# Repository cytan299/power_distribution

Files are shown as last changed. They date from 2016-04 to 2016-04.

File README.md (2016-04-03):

# Power Distribution Unit For Astrophotography

by C.Y. Tan 2016

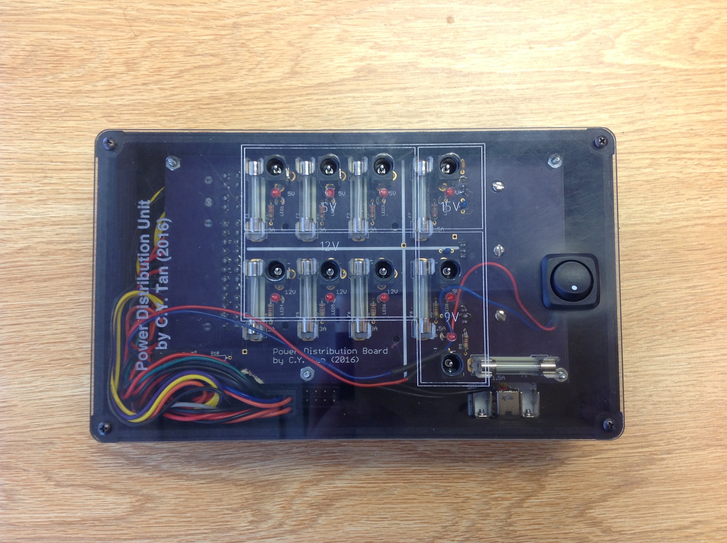
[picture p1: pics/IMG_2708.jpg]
Power Distribution Unit


I got really annoyed with the number of power bricks (or wall-warts)
that were required power my astrophotography setup:

* **LX200** 18V power supply. 
* **SBIG ST8300C** 12V power supply.
* **Field DeRotator** 9V power supply.
* **Dew Heater** 5V power supply.
* **Flat field box** 9V power supply.

I decided to consolidate the above into one box but with enough spare
outlets for future expansion.

## Goal

The goal is to build a power distribution unit that replaces all the
wall-warts that are necessary for running my astrophotography
setup. It should have extra outlets so that it can be used to power
other pieces of equipment in the future. All the outlets have to be
fused to protect itself as well as the connected equipment.

## Design

The power distribution unit is powered by a

* [External 240W 19.5V slim PA-9E PC supply](http://www.amazon.com/Original-PA-9E-Replacement-adapter-Notebook/dp/B00AVMYMUG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).

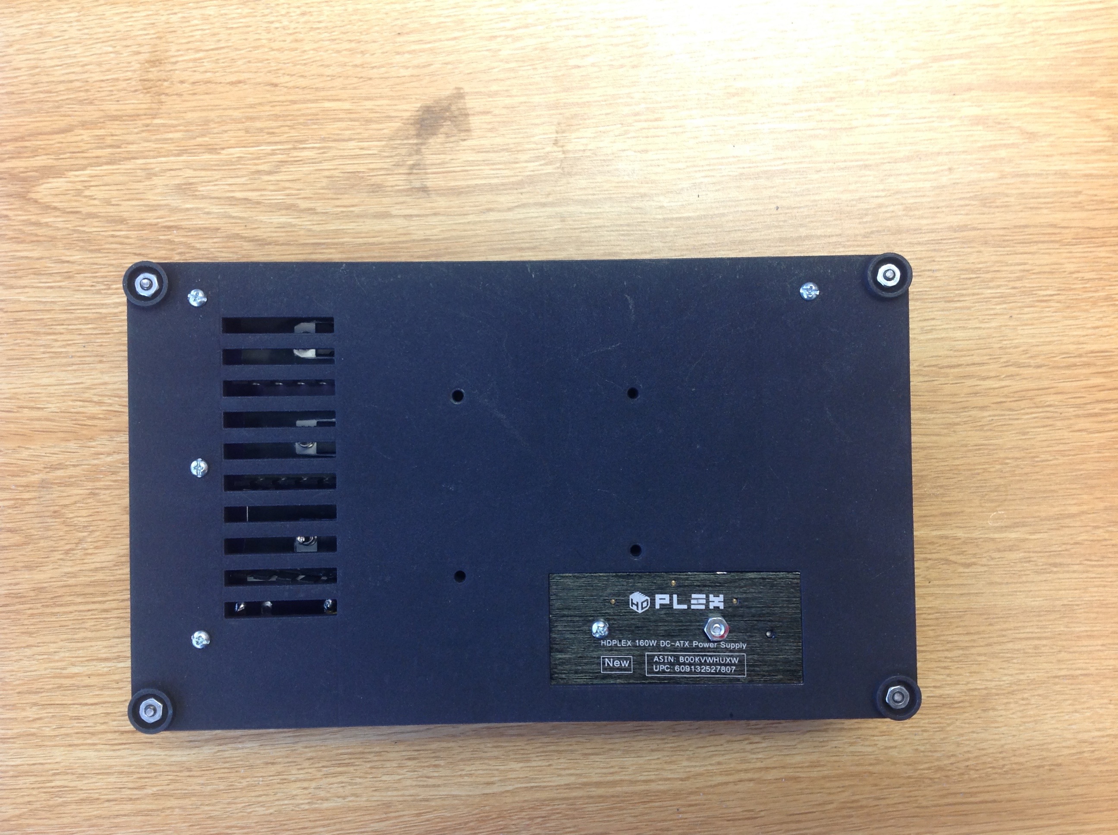
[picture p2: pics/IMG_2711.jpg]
Plex


The 19.5V from the above supply is connected to an internal fanless
[HDPLEX 160W ATX DC power supply](http://www.amazon.com/HDPLEX-DC-ATX-Power-Supply-16V-24V/dp/B00KVWHUXW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). The 5V and 12V supplies come directly from
the PLEX. The other 9V is linearly regulated from the 12V and the 15V
is linearly regulated from the 19.5V input voltage. The available voltage
outlets are listed below:

* Three 5V outlets
* Three 12V outlets
* Two 9 V outlets
* One 15 V outlet. I used this to power my LX200 classic. Although the
  front panel says that the voltage should be 18V, sources on the [web](http://www.skymtn.com/mapug-astronomy/MAPUG/Battery1.htm#anchor318436)
  recommend that a lower voltage be used to power it. Therefore I have
  reduced the voltage from 18V to 15V. Note: I was really shocked to
  measure >20V coming out from the Meade power supply for my LX200!

## Support

This is unsupported hardware. Build at your own peril! :)

You can submit questions or bug reports using the
[issues](https://github.com/cytan299/power_distribution/issues) tab on
the right and then click on **NEW**.

Have fun!

## Directory structure

* **case** The case design for the power distribution unit. It
  consists of a 3D STL file for the box and a SVG file for the
  cover. Source code for generating the 3D STL file in [OpenScad](http://www.openscad.org) format
  is included.
* **bom** Bill of materials for 1 power distribution unit.
* **eagle** Eagle schematic and board files.

## Other information

More information can be found in he *README.md* files in each
directory and the [wiki](https://github.com/cytan299/power_distribution/wiki/Power-Distribution-Unit) of this project on github.

## Copyright
All the software, documentation, and hardware that I have written is
copyright 2016 C.Y. Tan.

All software is released under GPLv3

All documentation is released under Creative Commons
Attribution-ShareAlike 3.0 Unported License or GNU Free
Documentation License, Version 1.3

All hardware is released under CERN Hardware Open License v1.2

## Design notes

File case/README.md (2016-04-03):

# 3D case

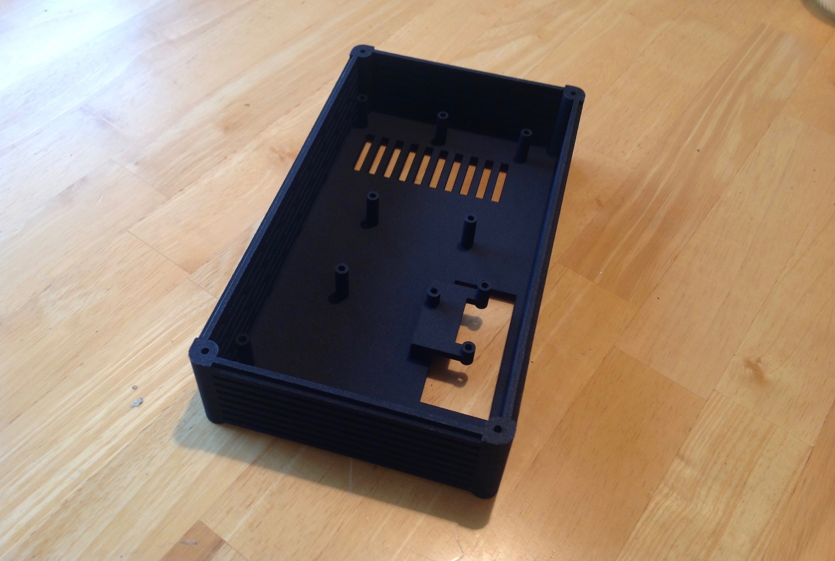
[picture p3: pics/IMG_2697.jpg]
3D Case View 1


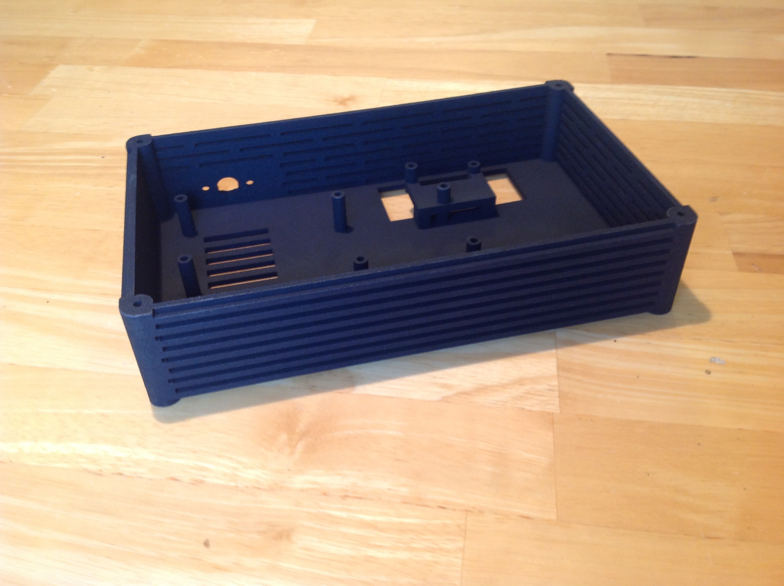
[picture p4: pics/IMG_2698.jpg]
3D Case View 2


This is the 3D case that I designed for the power distribution. The
source code for generating the case is written in
[OpenScad](http://www.openscad.org) and saved in *3D_case.scad*.

The file *3D_case.stl* file can be uploaded to [Shapeways](http://www.shapeways.com) for manufacture. The material that I used is

* Black Strong & Flexible.

# Front cover

The front cover is in *ponoko_front_cover2.svg*. This file can be
uploaded to [Ponoko](http://www.ponoko.com) for manufacture. The material that I used is

* Acrylic - Light Gray TINT
* 3.0 mm thick
* P2 - 384.0 mm long x 384.0 mm wide

## Copyright

The case design is copyright 2016 C.Y. Tan and released under the CERN Open Hardware License v1.2

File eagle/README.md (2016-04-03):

# Eagle files

These are the eagle files that can be sent to pc board manufacturers to
be made. There is a free version of [eagle](http://cadsoftusa.com)
that can be downloaded to view the designs.

* **power_distribution** This is the schematic and layout of the power
  distribution system.

## Copyright

The schematic and board designs are copyright 2016 C.Y. Tan and
released under the CERN Open Hardware License v1.2

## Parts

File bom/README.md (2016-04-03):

# Bill of Materials

I present the estimated cost for building *one* power distribution unit here
to be $385. This is the lower bound for the cost of one such device
because, in practise, it is not possible to just buy 1 screw :) or is
cost effective to build just one board
[OshPark](http://www.oshpark.com). Plus, I did not include
tax or cost of shipping. I would imagine that if people banded
together to build multiple copies of this device, the cost will get
closer to $385.

The bom.ods file is readable using [LibreOffice Calc](http://www.libreoffice.org).

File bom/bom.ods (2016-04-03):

Part # | Description | Price each | # required | Cost of 1 | Bought from | Total cost of 1
PA-9E | 240 W slimline AC adaptor for Dell | $45.29 | 1 | $45.29 | www.amazon.com (http://www.amazon.com/gp/product/B00AVMYMUG?psc=1&redirect=true&ref_=oh_aui_detailpage_o00_s00) | $384.72
HDPLEX 160W | DC ATX PS | $48.00 | 1 | $48.00 | www.amazon.com (http://www.amazon.com/gp/product/B00KVWHUXW?psc=1&redirect=true&ref_=oh_aui_detailpage_o01_s00)
CP-028AH-ND | power jack | $0.87 | 9 | $7.86 | www.digikey.com
36-4250-ND | fuse block | $1.36 | 9 | $12.24
WM1362-ND | 24 position right angle header | $3.74 | 1 | $3.74
P551-ND | Red LED 3mm | $0.36 | 9 | $3.22
MC7809CTGOS-ND | 9V 1A regulator | $0.45 | 2 | $0.90
HS278-ND | 4.5W heatsink | $0.67 | 3 | $2.01
CF14JT330RCT-ND | 330 ohms resistor | $0.04 | 4 | $0.16
445-8621-ND | 0.33 uF cap | $0.32 | 3 | $0.96
507-1530-ND | 3A fuse | $0.33 | 6 | $2.00
EP501B-ND | 2.5 mm plug | $0.98 | 1 | $0.98
497-6040-5-ND | 15V 2 A voltage regulator | $0.84 | 1 | $0.84
BC1154CT-ND | 0.1 uF cap | $0.15 | 1 | $0.15
WM1352-ND | 4 position 4.2 right angle header | $0.78 | 2 | $1.56
WM3701-ND | connector receptable 4 position dual | $0.31 | 1 | $0.31
WM2501-ND | female connectors for receptacle | $0.18 | 4 | $0.73
CP3-1000-ND | 2.1 mm female plug | $1.05 | 4 | $4.21
SC1388-ND | 2.1 mm power plug (collar) | $7.00 | 1 | $7.00
839-1170-ND | 2.1 mm 6 inch cable assembly | $2.43 | 8 | $19.44
SGFxcdey | PC boards | $46.67 | 1 | $46.67 | www.oshpark.com
2750693 | SPST rocker switch | $3.49 | 1 | $3.49 | www.radioshack.com
2701022 | 1.5A slow blow fuse | $0.87 | 3 | $2.62
 | 1k resistor | $0.05 | 5 | $0.25
 | Front cover | $12.20 | 1 | $12.20 | www.ponoko.com
30699994885 | Black oxide 4-40*2 inches machine screw | $0.40 | 4 | $1.60 | www.homedepot.com
887480021219 | machine screw nut 4-40 | $0.11 | 4 | $0.43
887480029819 | Machine screw 4-40 1.25 inch | $0.30 | 9 | $2.66 | www.homedepot.com
30699994380 | Machine screw black oxide 4-4 7/8” | $0.34 | 2 | $0.68
1260606 | 3D case | $152.53 | 1 | $152.53 | www.shapeways.com

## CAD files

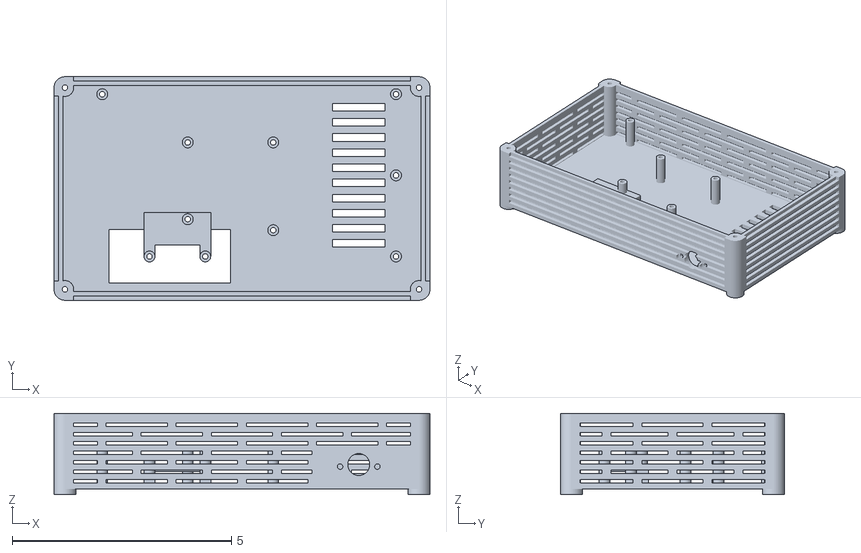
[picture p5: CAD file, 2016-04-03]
case/3D_case.stl
8.57 x 5.10 x 1.85

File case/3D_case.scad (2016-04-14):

/*
    3D_case.scad is the code to generate a 3D case for the power distribution unit.
    Copyright (C) 2016  C.Y. Tan
    Contact: cytan299@yahoo.com

    This file is part of 3D case power distribution

    3D_case is free software: you can redistribute it and/or modify
    it under the terms of the GNU General Public License as published by
    the Free Software Foundation, either version 3 of the License, or
    (at your option) any later version.

    3D_case is distributed in the hope that it will be useful,
    but WITHOUT ANY WARRANTY; without even the implied warranty of
    MERCHANTABILITY or FITNESS FOR A PARTICULAR PURPOSE.  See the
    GNU General Public License for more details.

    You should have received a copy of the GNU General Public License
    along with 3D_case.  If not, see <http://www.gnu.org/licenses/>.

*/
$fn=100;

// constants
Box_round_r = 0.25;
Box_x = 8.575;
Box_y = 5.10;
Box_t = 0.125; // bottom thickness
Box_wall_t = 0.2; // wall thickness
Box_h = 1.6; // height of box (excludes bottom thickness)

Box_screw_hole_r = 0.0625;

/*
  rectangle
*/
module roundedRect(size, radius)
{
x = size[0];
y = size[1];
z = size[2];

linear_extrude(height=z)
hull()
{
    // place 4 circles in the corners, with the given radius
    translate([(-x/2)+(radius/2), (-y/2)+(radius/2), 0])
    circle(r=radius);

    translate([(x/2)-(radius/2), (-y/2)+(radius/2), 0])
    circle(r=radius);

    translate([(-x/2)+(radius/2), (y/2)-(radius/2), 0])
    circle(r=radius);

    translate([(x/2)-(radius/2), (y/2)-(radius/2), 0])
    circle(r=radius);
}
}

/*
  Standoff
*/
module standoff(xyz, height, radius, hole_radius)
{
  translate(xyz) 
  difference(){
    cylinder(h=height, r=radius);
    cylinder(h=1.5*height, r=hole_radius);
  };
}

// Make the bottom of the case
module make_bottom() {
  difference() {
    roundedRect([Box_x - Box_round_r, Box_y - Box_round_r, Box_t], Box_round_r);
    
    // the screw holes for the PCB
    translate([-3.1875,2.15, 0]) cylinder(h=3*Box_t, r=Box_screw_hole_r, center = true);
   
    translate([3.5125, 2.15, 0]) cylinder(h=3*Box_t, r=Box_screw_hole_r, center = true);
    
    translate([3.5125,0.3, 0]) cylinder(h=3*Box_t, r=Box_screw_hole_r, center = true);
    
    translate([3.5125,-1.550, 0]) cylinder(h=3*Box_t, r=Box_screw_hole_r, center = true);
    
    translate([0.7125,-0.95, 0]) cylinder(h=3*Box_t, r=Box_screw_hole_r, center = true);
    
    translate([-1.2375,-0.7, 0]) cylinder(h=3*Box_t, r=Box_screw_hole_r, center = true);
    
    translate([-1.2375,1.05, 0]) cylinder(h=3*Box_t, r=Box_screw_hole_r, center = true);
    
    translate([0.7125,1.05, 0]) cylinder(h=3*Box_t, r=Box_screw_hole_r, center = true);
    
    // the screw holes for the front cover
    translate([-4.0375, -2.30, 0]) cylinder(h=3*Box_t, r=Box_screw_hole_r, center = true);
    
    translate([4.0375, -2.30, 0]) cylinder(h=3*Box_t, r=Box_screw_hole_r, center = true);
    
    translate([4.0375, 2.30, 0]) cylinder(h=3*Box_t, r=Box_screw_hole_r, center = true);
    
    translate([-4.0375, 2.30, 0]) cylinder(h=3*Box_t, r=Box_screw_hole_r, center = true);
    
    // rectangular hole for the switching PS
    translate([-3.0375, -2.15, 0]) cube(size=[2.77, 1.21, 3*Box_t], center = false);
    
    // cooling slots
    for(i=[0:9]){
      translate([2.0625, 1.7663 - i*0.345, 0]) cube(size=[1.20, 0.1725, 3*Box_t],    center = false);
    }   

  }
}

module make_standoffs()
{
  // standoffs for the PCB
  PCB_standoff_height = 0.775;
  PCB_standoff_radius = 0.125;
  PCB_standoff_hole_radius = 0.0625;
  
  standoff([-3.1875,2.15,Box_t], 
           PCB_standoff_height, 
           PCB_standoff_radius,
           PCB_standoff_hole_radius);
  
  standoff([3.5125, 2.15,Box_t], 
           PCB_standoff_height, 
           PCB_standoff_radius,
           PCB_standoff_hole_radius);
  
  
  standoff([3.5125,0.3,Box_t], 
           PCB_standoff_height, 
           PCB_standoff_radius,
           PCB_standoff_hole_radius);
  
  
  standoff([3.5125,-1.550,Box_t], 
           PCB_standoff_height, 
           PCB_standoff_radius,
           PCB_standoff_hole_radius);
  
  standoff([0.7125,-0.95,Box_t], 
           PCB_standoff_height, 
           PCB_standoff_radius,
           PCB_standoff_hole_radius);
  
  standoff([-1.2375,-0.7,Box_t], 
           PCB_standoff_height, 
           PCB_standoff_radius,
           PCB_standoff_hole_radius);
  
  standoff([-1.2375,1.05,Box_t], 
           PCB_standoff_height, 
           PCB_standoff_radius,
           PCB_standoff_hole_radius);
  
  standoff([0.7125,1.05,Box_t], 
           PCB_standoff_height, 
           PCB_standoff_radius,
           PCB_standoff_hole_radius);
           
  // ****standoff for the PS  
  
  // have a cross bar to strengthen the PS standoffs
  difference() {
   translate([-2.2342, -1.2850, 0.4]) 
           cube(size=[1.5217, 0.735, 0.175], center = false);
    // rehole a standoff
    translate([-1.2375, -0.7, 0]) cylinder(h=3*Box_h, r=Box_screw_hole_r, center = true);
  }
            
  standoff([-0.8375, -1.55, 0.325],
           0.575,
           PCB_standoff_radius,
           PCB_standoff_hole_radius);
  difference(){
    translate([-0.9625, -1.55, 0]) 
           cube(size=[2*PCB_standoff_radius, 1.0, 0.575], center = false);
   
    translate([-1.0875, -1.65, 0]) 
           cube(size=[4*PCB_standoff_radius, 0.71, 0.4], center = false);
    
    // rehole the standoff
    translate([-0.8375, -1.55, 0]) cylinder(h=3*Box_h, r=Box_screw_hole_r, center = true);
    
  }  
  
  standoff([-2.1092, -1.55, 0.325],
           0.4,
           PCB_standoff_radius,
           PCB_standoff_hole_radius);
  difference(){
    translate([-2.2342, -1.55, 0]) 
           cube(size=[2*PCB_standoff_radius, 1.0, 0.575], center = false);
    
    translate([-2.3592, -1.65, 0]) 
           cube(size=[4*PCB_standoff_radius, 0.71, 0.4], center = false);
    
    // rehole the standoff
    translate([-2.1092, -1.55, 0]) cylinder(h=3*Box_h, r=Box_screw_hole_r, center = true);
                 
  }
  
  
  
  // standoffs for the front cover
  FC_standoff_radius = 0.2;
  FC_standoff_hole_radius = 0.0625;
  
  standoff([-4.0375, 2.30, Box_t], 
           Box_h, 
           FC_standoff_radius,
           FC_standoff_hole_radius);
           
  standoff([4.0375, 2.30, Box_t], 
           Box_h, 
           FC_standoff_radius,
           FC_standoff_hole_radius);
           
  standoff([4.0375, -2.30, Box_t], 
           Box_h, 
           FC_standoff_radius,
           FC_standoff_hole_radius);
           
  standoff([-4.0375, -2.30, Box_t], 
           Box_h, 
           FC_standoff_radius,
           FC_standoff_hole_radius);
           
   
}
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

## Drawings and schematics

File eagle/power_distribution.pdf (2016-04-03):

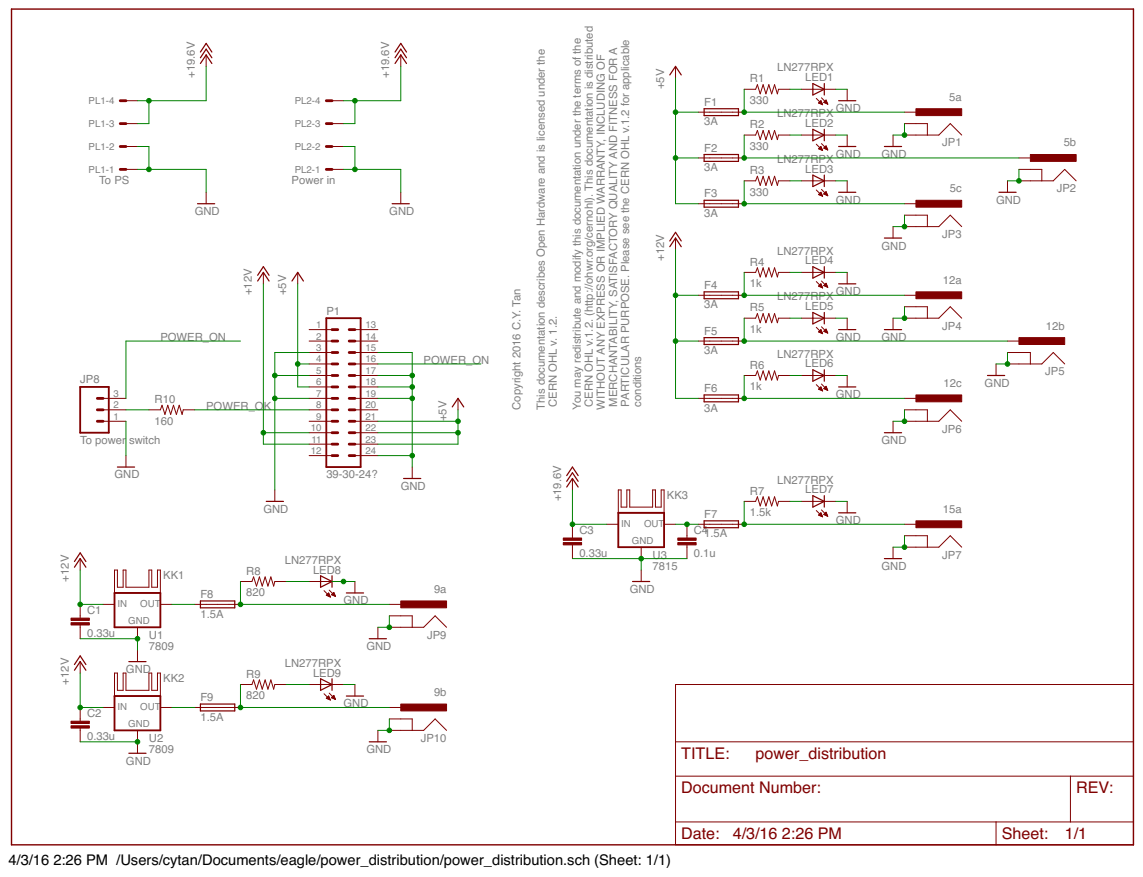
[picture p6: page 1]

Copyright 2016 C.Y. Tan This documentation describes Open Hardware and is licensed under the CERN OHL v. 1.2. You may redistribute and modify this documentation under the terms of the CERN OHL v.1.2. (http:/ ohwr.org/cernohl). This documentation is distributed WITHOUT ANY EXPRESS O

R PURPOSE. Please see the CERN OHL v.1.2 for applicable

22
23

Document Number: | REV:

Date: 4/3/16 2:26 PM | Sheet: 1/1

4/3/16 2:26 PM /Users/cytan/Documents/eagle/power_distribution/power_distribution.sch (Sheet: 1/1)

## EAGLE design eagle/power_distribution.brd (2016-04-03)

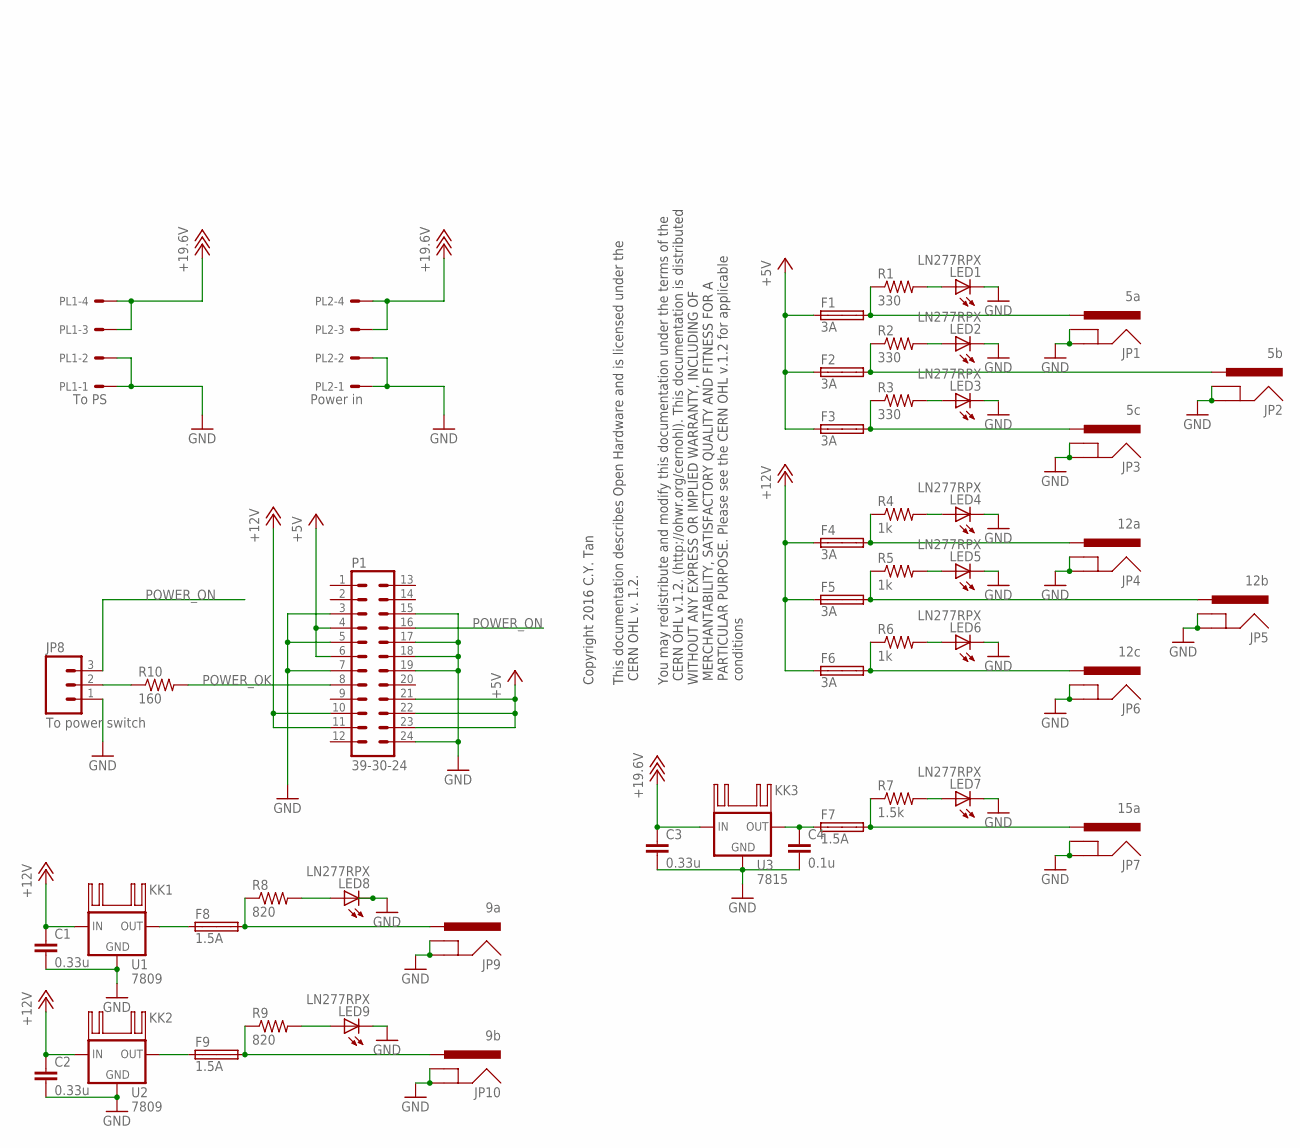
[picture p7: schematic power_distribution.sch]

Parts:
C1, C2, C3: 0.33u; CAP-PTH-5MM
C4: 0.1u; CAP-PTH-5MM
F1, F2, F3, F4, F5, F6: 3A; SH32
F7, F8, F9: 1.5A; SH32
JP1: 5a; POWER_JACK_V_PTH
JP2: 5b; POWER_JACK_V_PTH
JP3: 5c; POWER_JACK_V_PTH
JP4: 12a; POWER_JACK_V_PTH
JP5: 12b; POWER_JACK_V_PTH
JP6: 12c; POWER_JACK_V_PTH
JP7: 15a; POWER_JACK_V_PTH
JP8: To power switch; 1X03
JP9: 9a; POWER_JACK_V_PTH
JP10: 9b; POWER_JACK_V_PTH
KK1, KK2, KK3: TO-220_HEATSINK_4W; TO-220-HEATSINK-4W
LED1, LED2, LED3, LED4, LED5, LED6, LED7, LED8, LED9: LN277RPX; LED3MM
P1: 39-30-24; 39-30-?24?
PL1: To PS; 5569-4
PL2: Power in; 5569-4
R1, R2, R3: 330; 0207/10
R4, R5, R6: 1k; 0207/10
R7: 1.5k; 0207/10
R8, R9: 820; 0207/10
R10: 160; 0207/10
U1, U2: 7809; TO-220-ALT
U3: 7815; TO-220-ALT

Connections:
+5V: F1.1A, F2.1A, F3.1A, P1.4, P1.6, P1.21, P1.22, P1.23
+12V: C1.1, C2.1, F4.1A, F5.1A, F6.1A, P1.10, P1.11, U1.IN, U2.IN
+18V: C3.1, PL1.3, PL1.4, PL2.3, PL2.4, U3.IN
GND: C1.2, C2.2, C3.2, C4.2, JP1.GND, JP1.GNDBREAK, JP2.GND, JP2.GNDBREAK, JP3.GND, JP3.GNDBREAK, JP4.GND, JP4.GNDBREAK, JP5.GND, JP5.GNDBREAK, JP6.GND, JP6.GNDBREAK, JP7.GND, JP7.GNDBREAK, JP8.1, JP9.GND, JP9.GNDBREAK, JP10.GND, JP10.GNDBREAK, LED1.K (C), LED2.K (C), LED3.K (C), LED4.K (C), LED5.K (C), LED6.K (C), LED7.K (C), LED8.K (C), LED9.K (C), P1.3, P1.5, P1.7, P1.15, P1.17, P1.18, P1.19, P1.24, PL1.1, PL1.2, PL2.1, PL2.2, U1.GND, U2.GND, U3.GND
unnamed: F1.2A, JP1.PWR, R1.1
unnamed: F2.2A, JP2.PWR, R2.1
unnamed: F3.2A, JP3.PWR, R3.1
unnamed: LED1.A, R1.2
unnamed: LED2.A, R2.2
unnamed: LED3.A, R3.2
unnamed: F4.2A, JP4.PWR, R4.1
unnamed: F5.2A, JP5.PWR, R5.1
unnamed: F6.2A, JP6.PWR, R6.1
unnamed: LED4.A, R4.2
unnamed: LED5.A, R5.2
unnamed: LED6.A, R6.2
unnamed: F8.1A, U1.OUT
unnamed: F7.2A, JP7.PWR, R7.1
unnamed: LED7.A, R7.2
unnamed: F8.2A, JP9.PWR, R8.1
unnamed: LED8.A, R8.2
unnamed: JP8.2, R10.1
unnamed: F9.1A, U2.OUT
unnamed: F9.2A, JP10.PWR, R9.1
unnamed: LED9.A, R9.2
unnamed: C4.1, F7.1A, U3.OUT
POWER_OK: P1.8, R10.2
POWER_ON: JP8.3, P1.16

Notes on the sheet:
Copyright 2016 C.Y. Tan This documentation describes Open Hardware and is licensed under the CERN OHL v. 1.2. You may redistribute and modify this documentation under the terms of the CERN OHL v.1.2. (http://ohwr.org/cernohl). This documentation is distributed WITHOUT ANY EXPRESS OR IMPLIED WARRANT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

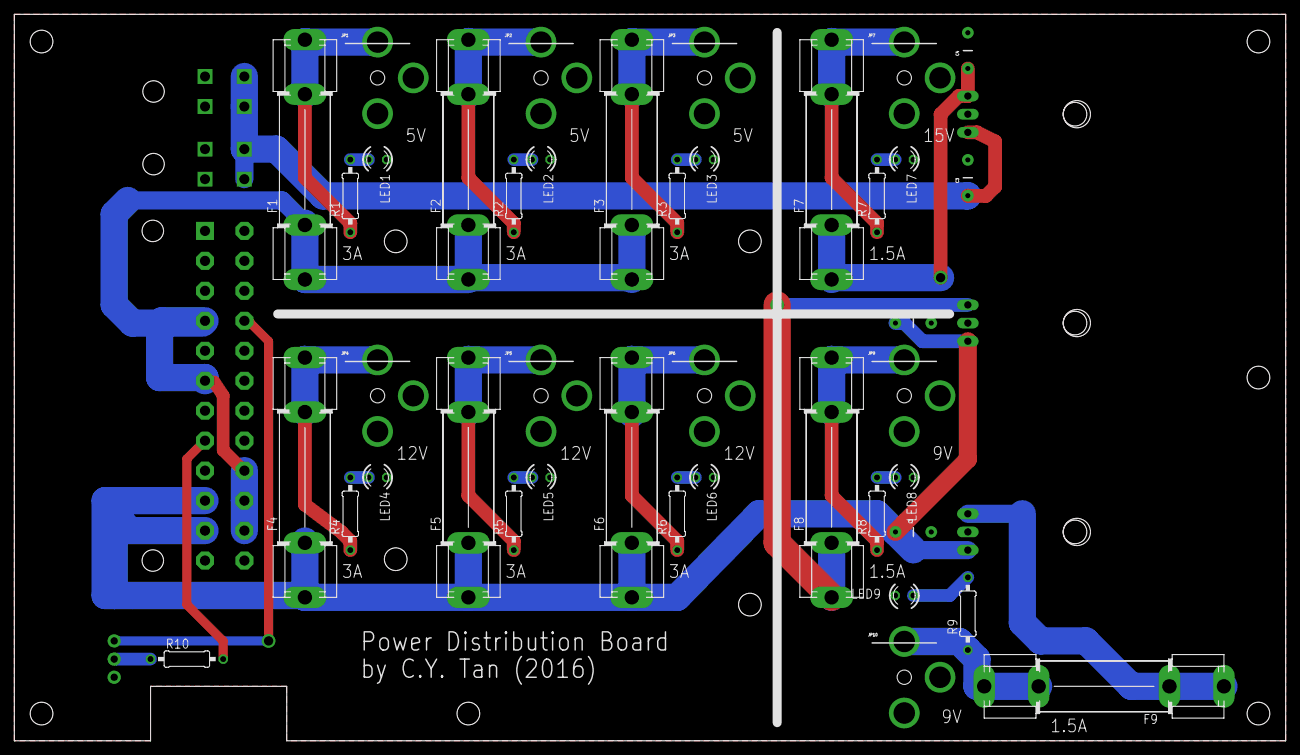
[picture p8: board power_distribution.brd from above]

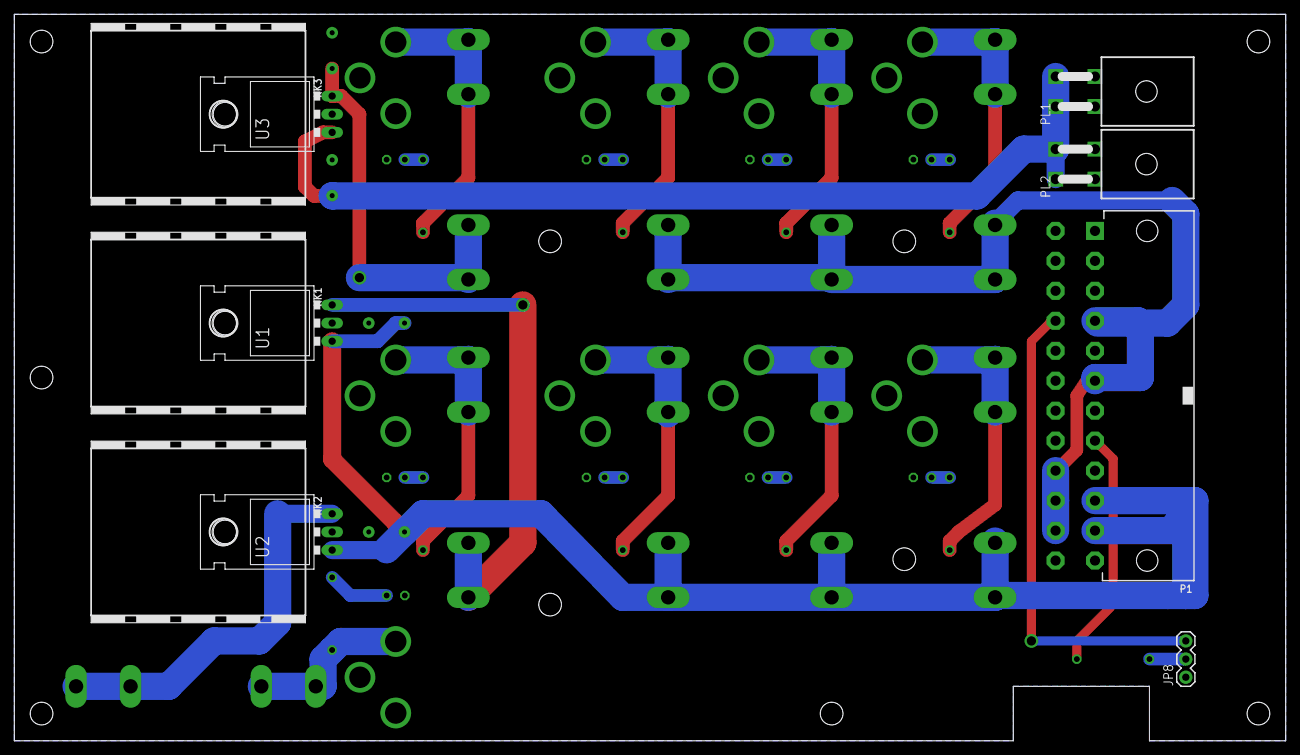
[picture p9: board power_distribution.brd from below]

Board: 2 copper layers, 177.8 x 101.6 mm, 51 parts (10 on the bottom side), 28 nets.

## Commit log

2016-04-03 Power Distribution Unit for Astrophotography
    [3D_case.scad, 3D_case.stl, bom.ods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]
2016-04-03 README.md: Updated link to photograph of power distribution unit. Plus small edits
2016-04-03 Updated README.md and case/README.md
2016-04-03 Updated README.md to point to power supply specs
2016-04-14 case: Updated GNU license in 3D_case.scad
    [3D_case.scad]

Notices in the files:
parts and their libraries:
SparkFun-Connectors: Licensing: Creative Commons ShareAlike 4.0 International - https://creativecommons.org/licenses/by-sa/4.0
